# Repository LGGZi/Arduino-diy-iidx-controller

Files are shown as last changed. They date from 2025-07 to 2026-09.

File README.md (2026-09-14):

# Arduino-diy-iidx-controller
(README_EN.md for English)
学着lizardbeans佬写代码，使用超频A类似的外壳设计做的IIDX手台，LR2、beatoraja、和本家都可用，功能上包含HID灯光。自己做出来的成本在300-400（去除部分工具费用的话），视选用的配件具体数值会有波动，游玩的效果很不错，算得上便宜好用。<br>
2025/10/10更新：<br>
加入SDVX版代码和CAD文件，其中CAD文件的外壳在亚克力材质下可能有一定的强度问题。<br>
加入SDVX和IIDX通用的12键2编码器版本PCB和代码。
2026/9/5更新:<br>
废弃旧设计，目前仅维护新电路板内容。<br>
旧版readme可去文件名带有“_legacy”的readme查看
## 实物图
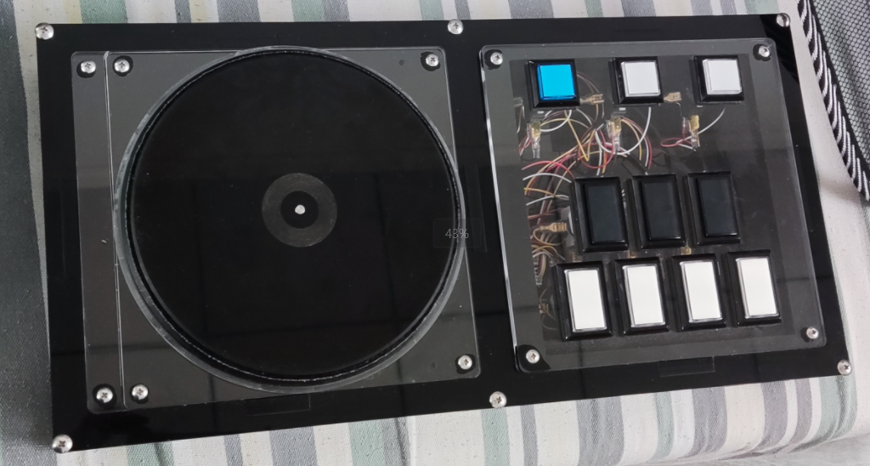
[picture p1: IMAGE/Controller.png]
<br><br>
## 目前已实现
1、一个画较为完善的电路板，嘉立创制作、原理图和PCB以及Gerber文件都放在`PCB&BOM`文件夹下。<br>
2、外壳的CAD文件。全亚克力外壳，包括转盘，转盘额外提供了一个可连接联轴器的版本，不需要的话不用切割。<br>
3、实现了多种输入模式的代码，具体功能在下一部分详细描述。<br>
## 控制器功能
1号键到4号键分别为不同模式，按住其中一个键并插入USB数据线即可进入不同模式，不同模式及其功能如下：<br>
------------------------------------------------------------------------------------<br>
* 模式1：手柄模拟量模式，此模式下会将按键映射为手柄的按钮，并将转盘映射为手柄x轴/y轴，转动转盘会视转动的方向和速度使手柄x轴/y轴平滑移动。<br>
* 模式2、3：三种不同灵敏度的手柄摇杆绝对值模式，按键与模式1相同，但转盘根据方向映射为按键和摇杆的极值，相当于是全按键模式。2和3模式区别为转盘灵敏度不同，2高敏，3低敏。<br>
* 模式4：键鼠模式，七个按键映射为键盘`z s x d c f v`，转盘映射为鼠标x轴和y轴，非常适合用于本家<br>

------------------------------------------------------------------------------------<br>
通过使用EEPROM实现了模式的记忆，插入时不选择模式（不按下按键）会从EEPROM中读取上次的模式并进入
可利用组合键开关灯光，开关灯光的函数为`lightswitch()`，默认为`(11,0,3,button_buf)`,即1、4、12按钮同时按下切换开关。
## 电路板使用说明
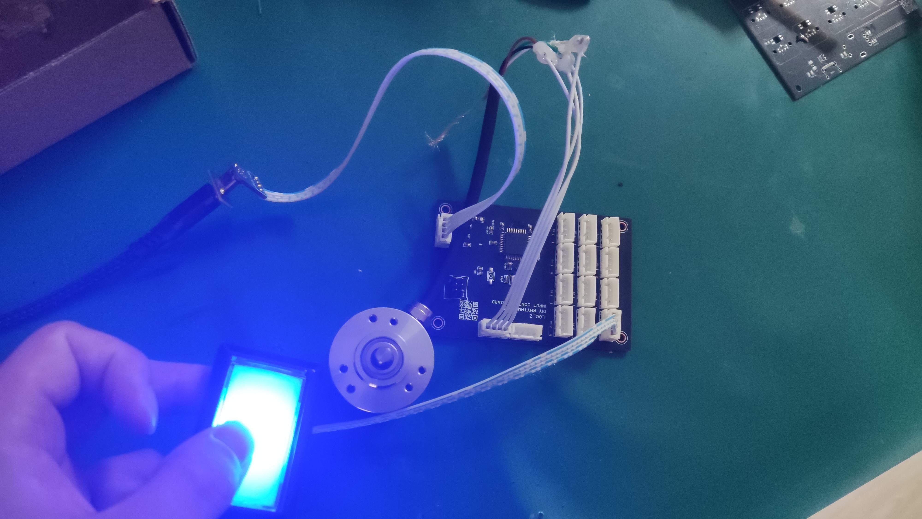
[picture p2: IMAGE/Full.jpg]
实物图<br><br>
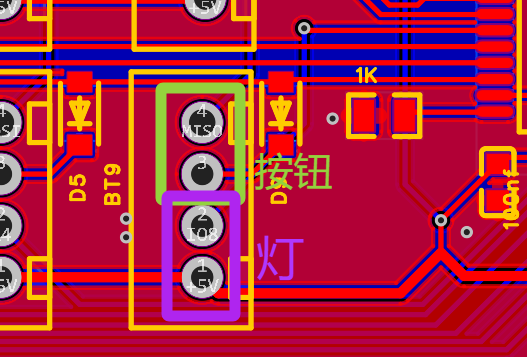
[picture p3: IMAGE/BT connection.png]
所有配件通过XH2.54的4pin借口连接，连接方式如下图<br><br>
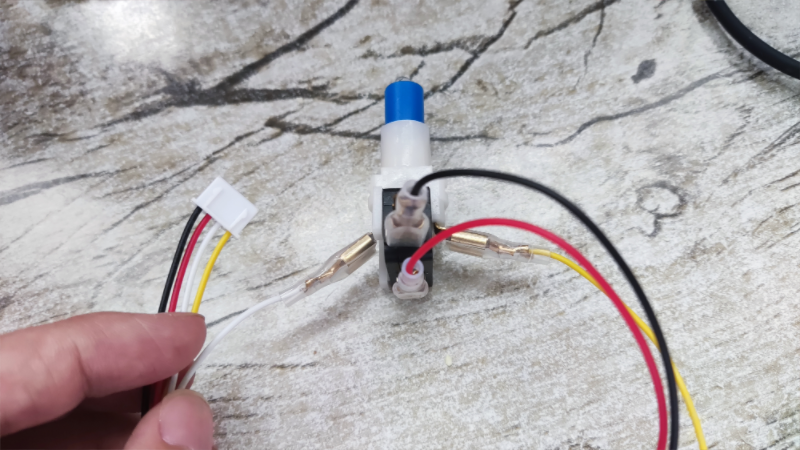
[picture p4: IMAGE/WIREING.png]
以按钮线举例如下图所示，公头防呆凸起面向上，左侧两个为连接微动的线，右侧两个为连接灯光的线，编码器的连接方式类似，根据上图连接即可<br><br>
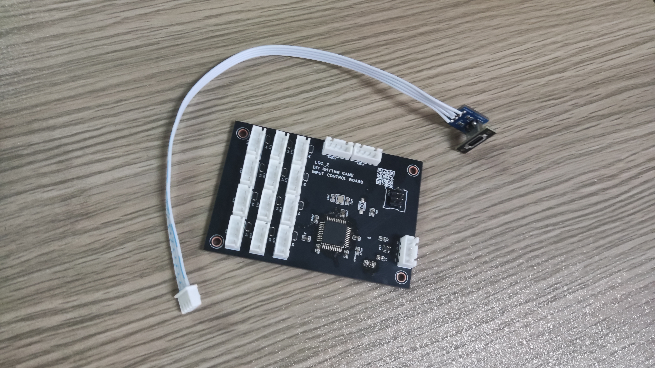
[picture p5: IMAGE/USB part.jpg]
USB部分以4Pin接口的形式引出，可外接USB模块<br><br>
USB模块的Gerber文件在`PCB&BOM`

## 外壳设计
全亚克力的外壳，框体板使用1cm亚克力切割，面板则在文件内标注了使用的亚克力厚度，转盘可与外壳共同切割，CAD内标注了防割倒角与螺丝孔用下沉，直接将CAD交付与激光切割的厂家即可。<br>
在框体之间的上下面板的螺丝孔之间加装50mm长的M4螺柱，这样即可实现上下板的连接和面板的安装<br>
转盘提供了使用法兰联轴器固定和仅依靠编码器D型轴柱联动的两种盘面，切割误差不太大的话仅依靠D型轴也能有不错的手感，只是因为盘体非固定的缘故不能倒置手台而已，由于编码器轴长和转盘盘座高度道问题，使用法兰联轴器版本的转盘可能需要额外使用垫片来下降编码器高度，否则转盘可能会悬空。<br>
我简单建模了一个转盘盘托，可以用3D打印机打印并代替CAD中的盘托文件在`3D_Model`中<br>
亚克力外壳分为大小两款，小款在`small`文件夹下，文件名带有3dprint的为使用3d打印盘托的外壳文件<br>

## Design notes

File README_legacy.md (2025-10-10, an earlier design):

# Arduino-diy-iidx-controller
(README_EN.md for English)
学着lizardbeans佬写代码，使用超频A类似的外壳设计做的IIDX手台，LR2、beatoraja、和本家都可用，功能上包含HID灯光。自己做出来的成本在300-400（去除部分工具费用的话），视选用的配件具体数值会有波动，游玩的效果很不错，算得上便宜好用。<br>
2025/10/10更新：<br>
加入SDVX版代码和CAD文件，其中CAD文件的外壳在亚克力材质下可能有一定的强度问题。<br>
加入SDVX和IIDX通用的12键2编码器版本PCB和代码。
## 实物图
<br><br>
## 目前已实现
1、一个画的很随便但可用的电路板，嘉立创制作、原理图和PCB以及Gerber文件都放在`PCB&BOM`文件夹下了。<br>
2、外壳的CAD文件。全亚克力外壳，包括转盘，转盘额外提供了一个可连接联轴器的版本，不需要的话不用切割。<br>
3、实现了多种输入模式的代码，具体功能在下一部分详细描述。<br>
## 控制器功能
按住start键（PCB上的BTA）加1到6号按键的其中一个键并插入USB数据线即可进入不同模式，不同模式及其功能如下：<br>
------------------------------------------------------------------------------------<br>
* 模式1：手柄模拟量模式，此模式下会将按键映射为手柄的按钮，并将转盘映射为手柄x轴，转动转盘会视转动的方向和速度使手柄x轴平滑移动。<br>
* 模式2-4：三种不同灵敏度的手柄摇杆绝对值模式，按键与模式1相同，但转盘根据方向映射为按键和摇杆的最左或最右，相当于是全按键模式。2到4三个模式区别为转盘灵敏度不同，2最快，4最慢。<br>
* 模式5：键鼠模式，七个按键映射为键盘zsxdcfv，转盘映射为鼠标x轴，非常适合用于本家<br>
* 模式6：自己搞着玩的，依旧是映射为键鼠，不过转盘换成了滚轮，别用。<br>

------------------------------------------------------------------------------------<br>
通过使用EEPROM实现了模式的记忆，插入时不按组合键会从EEPROM中读取上次的模式并进入

## 电路板使用说明
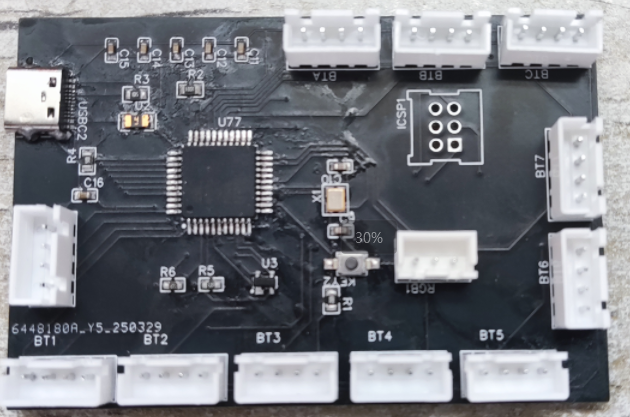
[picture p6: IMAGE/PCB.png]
实物图<br><br>
所有配件通过XH2.54的4pin借口连接，连接方式如下图<br><br>
以按钮线举例如下图所示，公头防呆凸起面向上，左侧两个为连接微动的线，右侧两个为连接灯光的线，编码器的连接方式类似，根据上图连接即可<br><br>
电路板上有可正反插的Type-C接口（虽然还是建议搞个延长线连外边用，有一种type-c延长线是刚好能卡在外壳侧板的开孔里的）

##外壳设计
全亚克力的外壳，框体板使用1cm亚克力切割，面板则在文件内标注了使用的亚克力厚度，转盘可与外壳共同切割，CAD内标注了防割倒角与螺丝孔用下沉，直接将CAD交付与激光切割的厂家即可。<br>
在框体之间的上下面板的螺丝孔之间加装50mm长的M4螺柱，这样即可实现上下板的连接和面板的安装<br>
转盘提供了使用法兰联轴器固定和仅依靠编码器D型轴柱联动的两种盘面，切割误差不太大的话仅依靠D型轴也能有不错的手感，只是因为盘体非固定的缘故不能倒置手台而已，由于编码器轴长和转盘盘座高度道问题，使用法兰联轴器版本的转盘可能需要额外使用垫片来下降编码器高度，否则转盘可能会悬空。<br>
（附图等之后再此下单买外壳的时候再拍）<br>

## 代码结构
以后再施工，懒了💀

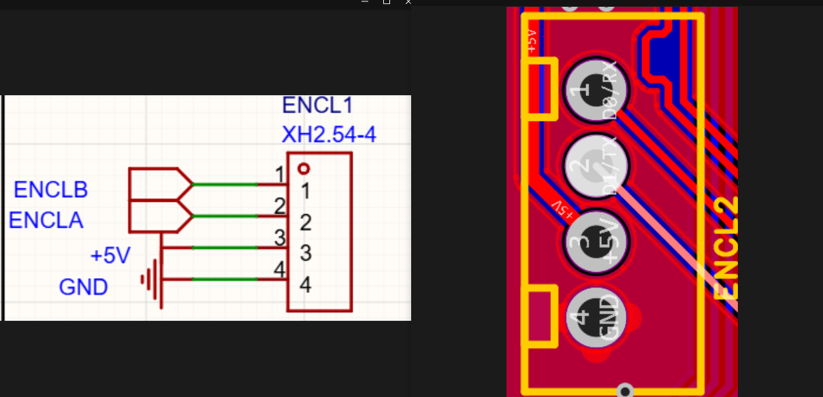
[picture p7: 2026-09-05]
IMAGE/Encoder connection.png

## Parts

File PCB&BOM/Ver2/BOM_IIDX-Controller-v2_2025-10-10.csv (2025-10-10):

ID | Name | Designator | Footprint | Quantity | Manufacturer Part | Manufacturer | Supplier | Supplier Part | Price
1 | XH2.54-4 | BT1,BT2,BT3,BT4,BT5,BT6,BT7,BT8,BT9,BTA,BTB,BTC,ENCL1,ENCL2,USB | CONN-TH_XH2.54-4 | 15 | XH2.54-4 | null | LCSC | C9900012082
2 | 22pF | C9,C10 | C0603 | 2 | CL10C220JB81PNC | SAMSUNG | LCSC | C170132 | 0.066
3 | 100nF | C11,C12,C13,C14 | C0603 | 4 | CL10B104JB8NNNC | SAMSUNG | LCSC | C24452 | 0.0591
4 | 470nF | C15 | C0603 | 1 | CL10B474KA8NNNC | SAMSUNG | LCSC | C1623 | 0.0461
5 | 1uF | C16 | C0603 | 1 | CL10A105KB8NNNC | SAMSUNG | LCSC | C15849 | 0.0311
6 | SOD4002-SH | D1,D2,D3,D4,D5,D6,D7,D8,D9,DA,DB,DC | SOD-123F_L2.8-W1.8-LS3.7-RD | 12 | SOD4002-SH | LRC(乐山无线电) | LCSC | C154996 | 0.1075
7 | XH2_54-2X3P直插 | ICSP1 | CONN-TH_XH2.54-2X3P | 1 | XH2_54-2X3P直插 | null | LCSC | C9900001046
8 | Switch3x4x2 | KEY2 | KEY-3.0*4.0 | 1 | Switch3x4x2 | ReliaPro | LCSC | C26638 | 0.1628
9 | 10K | R1 | R0805 | 1 | 0805W8F1002T5E | UniOhm | LCSC | C17414 | 0.0114
10 | 1K | R2 | R0805 | 1 | TC0525F1001T5E | UniOhm | LCSC | C75781 | 0.0776
11 | 22 | R5,R6 | R0603 | 2 | 0603WAF220JT5E | UniOhm | LCSC | C23345 | 0.0062
12 | 铜柱M3*12+3 | U1,U4,U5,U6 | TH_BD4.7-D3.0 | 4 | M3*12+3 | 国产 | LCSC | C110574 | 0.2255
13 | MF-NSMF050-2 | U2 | F1206 | 1 | MF-NSMF050-2 | BOURNS | LCSC | C75464 | 0.1976
14 | PRTR5V0U2X | U3 | SOT-143_L2.9-W1.3-P1.92-LS2.3-BL | 1 | PRTR5V0U2X | Yenji Elec | LCSC | C330092 | 0.5828
15 | ATMEGA32U4-AU | U77 | QFP-44_L10.0-W10.0-P0.80-LS13.2-BL | 1 | ATMEGA32U4-MU | MICROCHIP | LCSC | C112161 | 34.13
16 | 16MHz | X1 | OSC-SMD_4P-L3.2-W2.5-BL | 1 | X322516MRB4SI | YXC | LCSC | C70562 | 0.5159

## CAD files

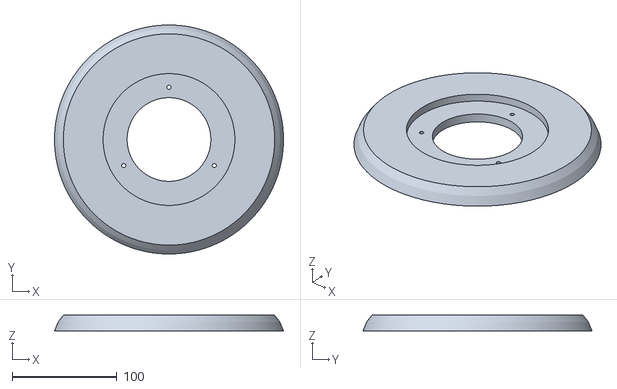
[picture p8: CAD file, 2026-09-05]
3D_Model/Ttable15mmhigh.stl
219.0 x 219.0 x 15.0

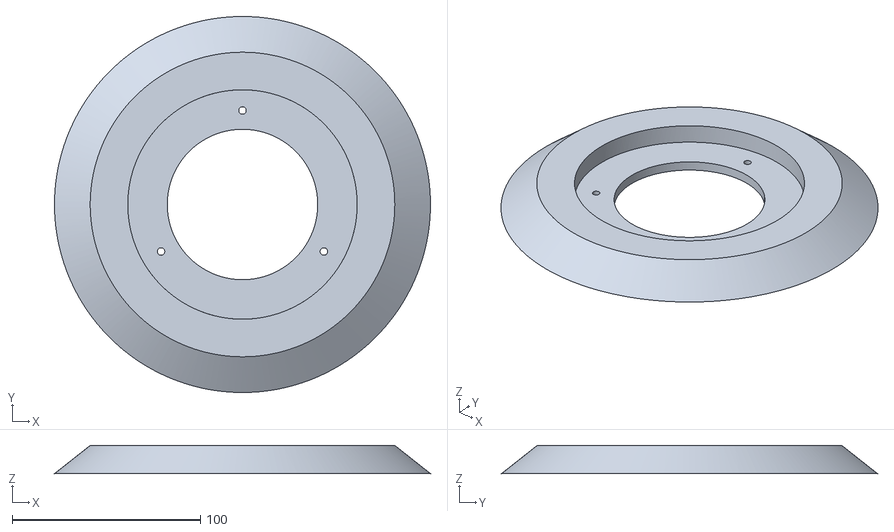
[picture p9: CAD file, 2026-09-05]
3D_Model/Ttable160TT 15hight.stl
200.0 x 200.0 x 15.0

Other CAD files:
Frame_cad/SDVX/FULL FRAME.dwg
Frame_cad/IIDX/panel 0.45cm mostly with 3dprint.dwg
Frame_cad/IIDX/small/drawing_frame_v3.dwg
Frame_cad/IIDX/frame plastic 1cm type-c.dwg
Frame_cad/IIDX/small/drawing_panel_v2_200TT_10key.dwg
Frame_cad/IIDX/frame plastic 1cm.dwg
Frame_cad/IIDX/small/drawing_panel_160TT_3dprint_10key.dwg
Frame_cad/IIDX/panel 0.45cm mostly.dwg
3D_Model/Ttable15mmhigh.dwg

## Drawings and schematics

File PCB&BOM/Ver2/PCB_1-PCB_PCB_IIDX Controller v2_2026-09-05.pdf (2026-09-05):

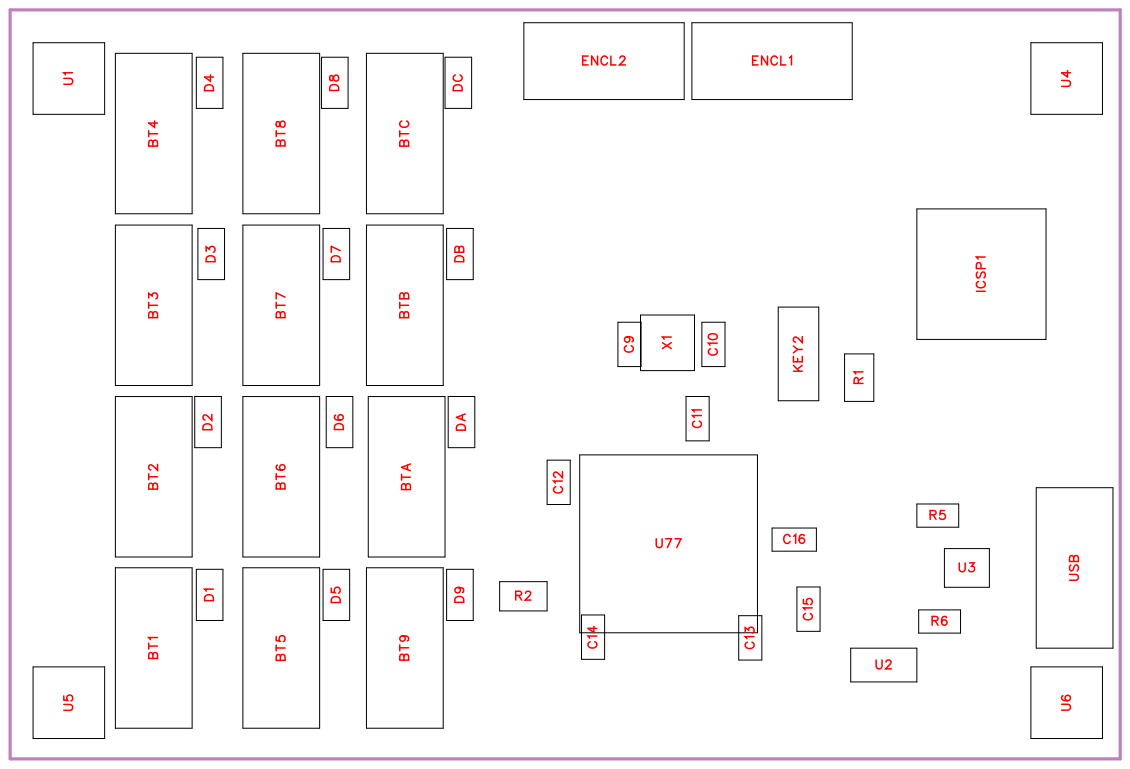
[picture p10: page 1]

No. | Quantity | Comment | Designator | Footprint | Value | Manufacturer Part | Manufacturer | Supplier Part | Supplier
1 | 15 | XH2.54-4 | BT1,BT2,BT3,BT4,BT5,BT6 ,BT7,BT8,BT9,BTA,BTB,BT C,ENCL1,ENCL2,USB | CONN-TH_X H2.54-4 | | XH2.54-4 | null | C990001208 2 | LCSC
2 | 2 | 22pF | C9,C10 | C0603 | | CL10C220JB 81PNC | SAMSUNG | C170132 | LCSC
3 | 4 | 100nF | C11,C12,C13,C14 | C0603 | | CL10B104JB 8NNNC | SAMSUNG | C24452 | LCSC
4 | 1 | 470nF | C15 | C0603 | | CL10B474KA 8NNNC | SAMSUNG | C1623 | LCSC
5 | 1 | 1uF | C16 | C0603 | | CL10A105KB 8NNNC | SAMSUNG | C15849 | LCSC
6 | 12 | SOD4002-S H | D1,D2,D3,D4,D5,D6,D7,D8, D9,DA,DB,DC | SOD-123F_L 2.8-W1.8-LS 3.7-RD | | SOD4002-S H | LRC(乐山无 线电) | C154996 | LCSC
7 | 1 | XH2_54-2X3 P直插 | ICSP1 | CONN-TH_X H2.54-2X3P | | XH2_54-2X3 P直插 | null | C990000104 6 | LCSC
8 | 1 | Switch3x4x2 | KEY2 | KEY-3.0*4.0 | | Switch3x4x2 | ReliaPro | C26638 | LCSC
9 | 1 | 10K | R1 | R0805 | | 0805W8F100 2T5E | UniOhm | C17414 | LCSC
10 | 1 | 1K | R2 | R0805 | | TC0525F100 1T5E | UniOhm | C75781 | LCSC
11 | 2 | 22 | R5,R6 | R0603 | | 0603WAF22 0JT5E | UniOhm | C23345 | LCSC
12 | 4 | 铜柱M3*12+3 | U1,U4,U5,U6 | TH_BD4.7-D 3.0 | | M3*12+3 | 国产 | C110574 | LCSC
13 | 1 | MF-NSMF05 0-2 | U2 | F1206 | | MF-NSMF05 0-2 | BOURNS | C75464 | LCSC
14 | 1 | PRTR5V0U2 X | U3 | SOT-143_L2. 9-W1.3-P1.9 2-LS2.3-BL | | PRTR5V0U2 X | Yenji Elec | C330092 | LCSC
15 | 1 | ATMEGA32U 4-AU | U77 | QFP-44_L10. 0-W10.0-P0. 80-LS13.2-B L | | ATMEGA32U 4-MU | MICROCHIP | C112161 | LCSC
16 | 1 | 16MHz | X1 | OSC-SMD_4 P-L3.2-W2.5-BL | | X322516MR B4SI | YXC | C70562 | LCSC

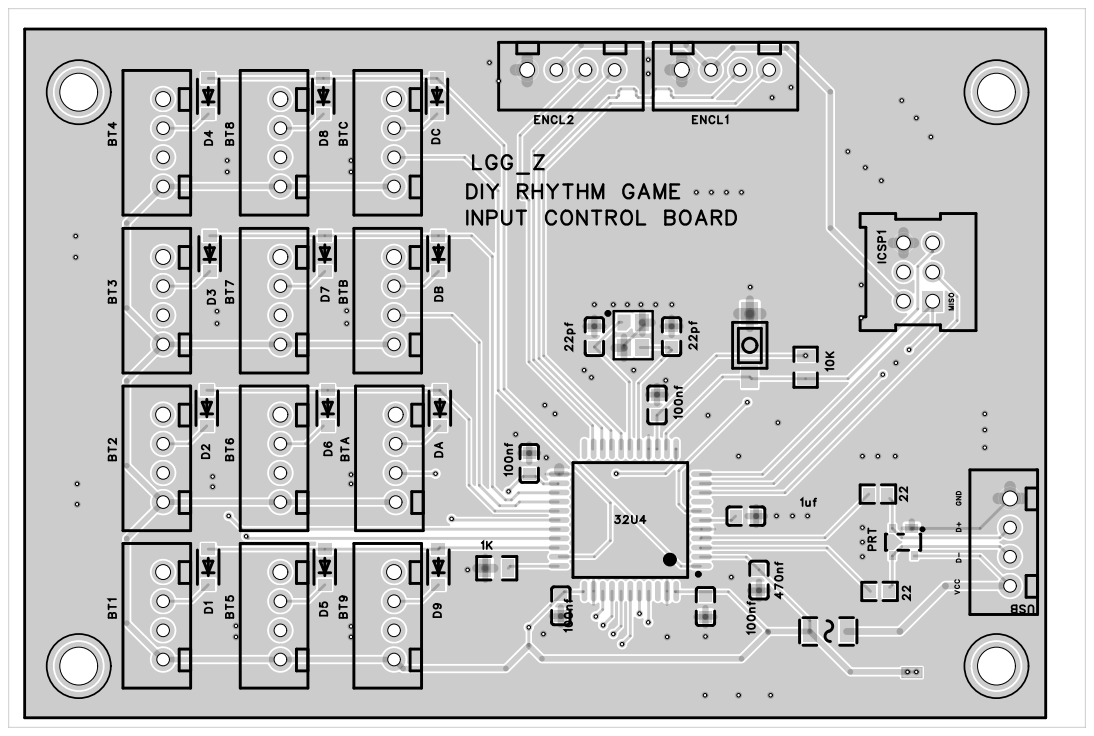
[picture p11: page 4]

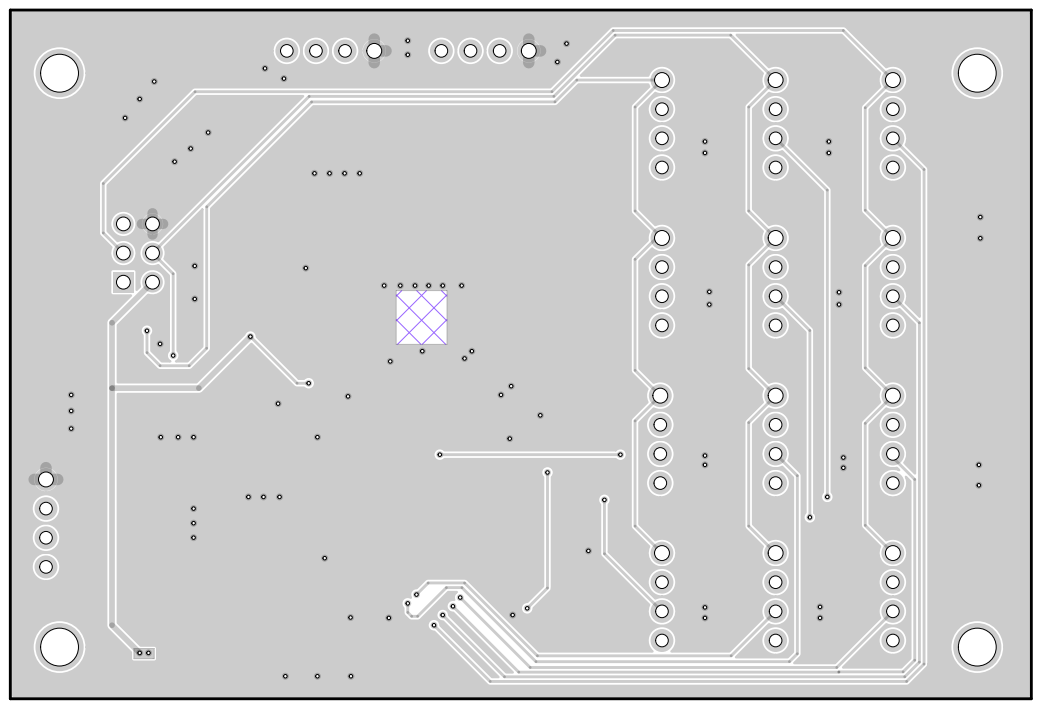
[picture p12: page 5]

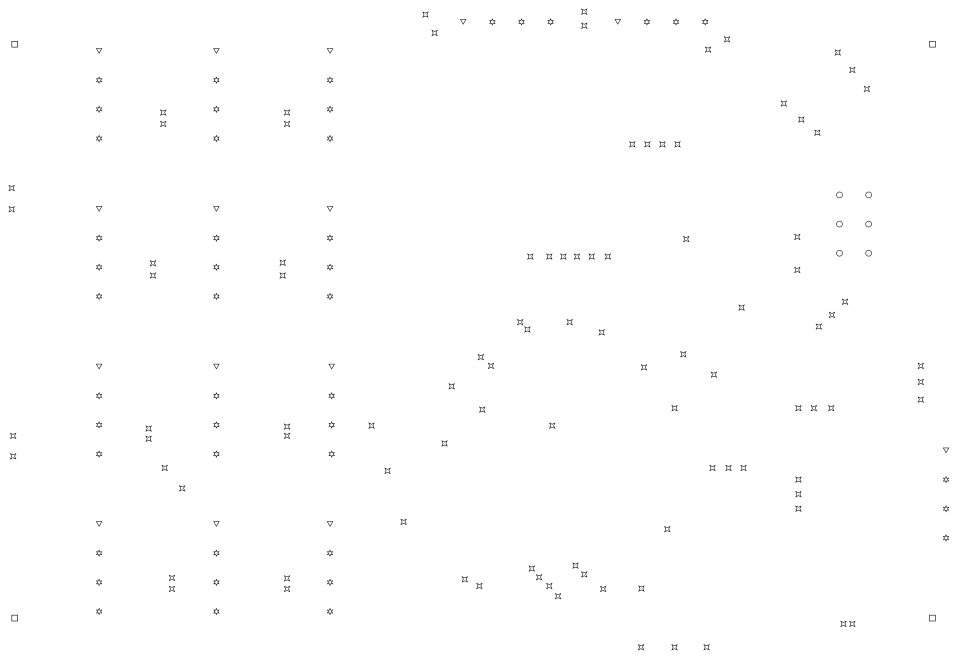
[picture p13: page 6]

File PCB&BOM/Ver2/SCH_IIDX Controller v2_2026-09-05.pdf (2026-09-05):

# ICSP

# ATMEGA32U4

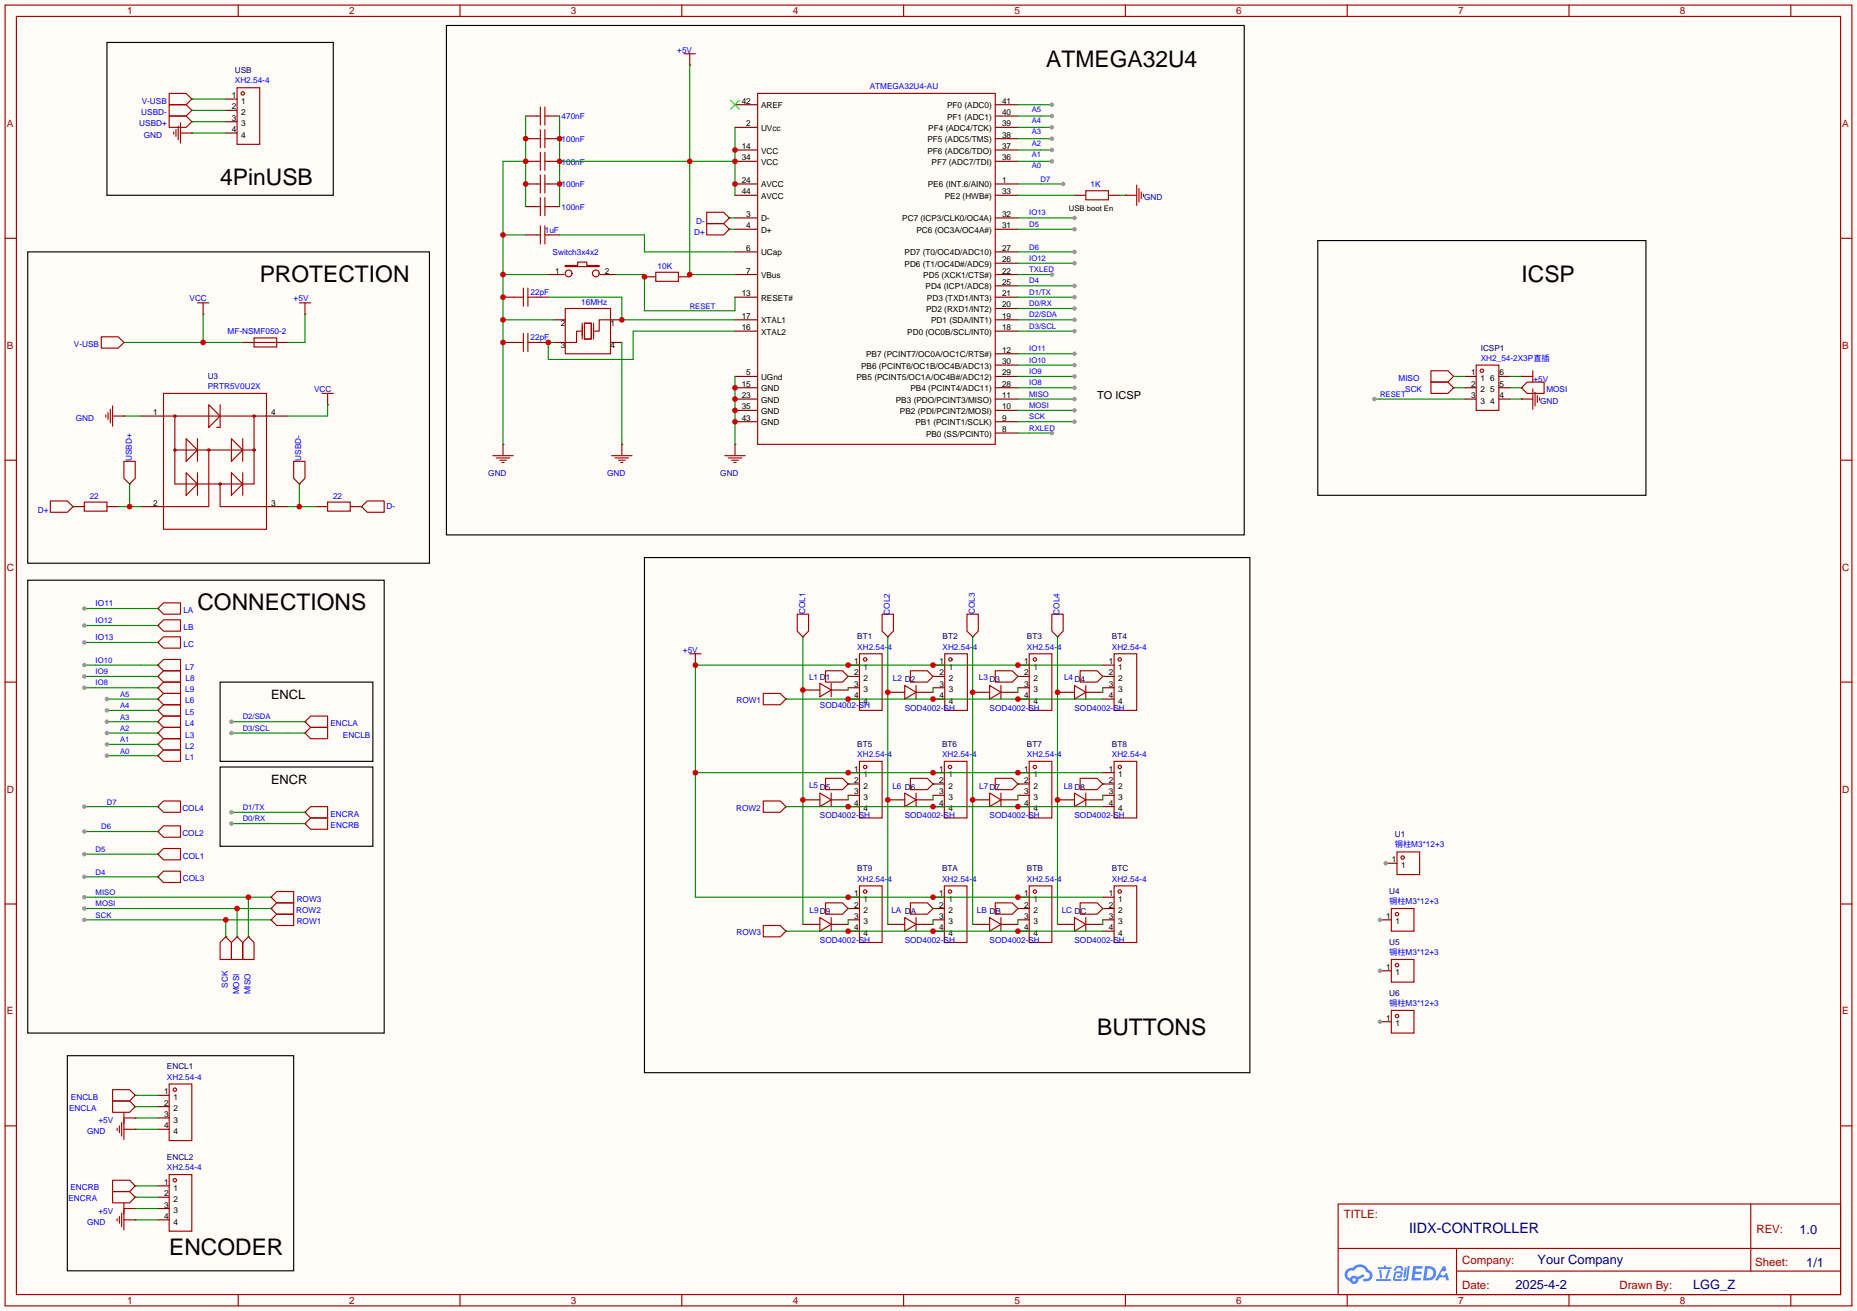
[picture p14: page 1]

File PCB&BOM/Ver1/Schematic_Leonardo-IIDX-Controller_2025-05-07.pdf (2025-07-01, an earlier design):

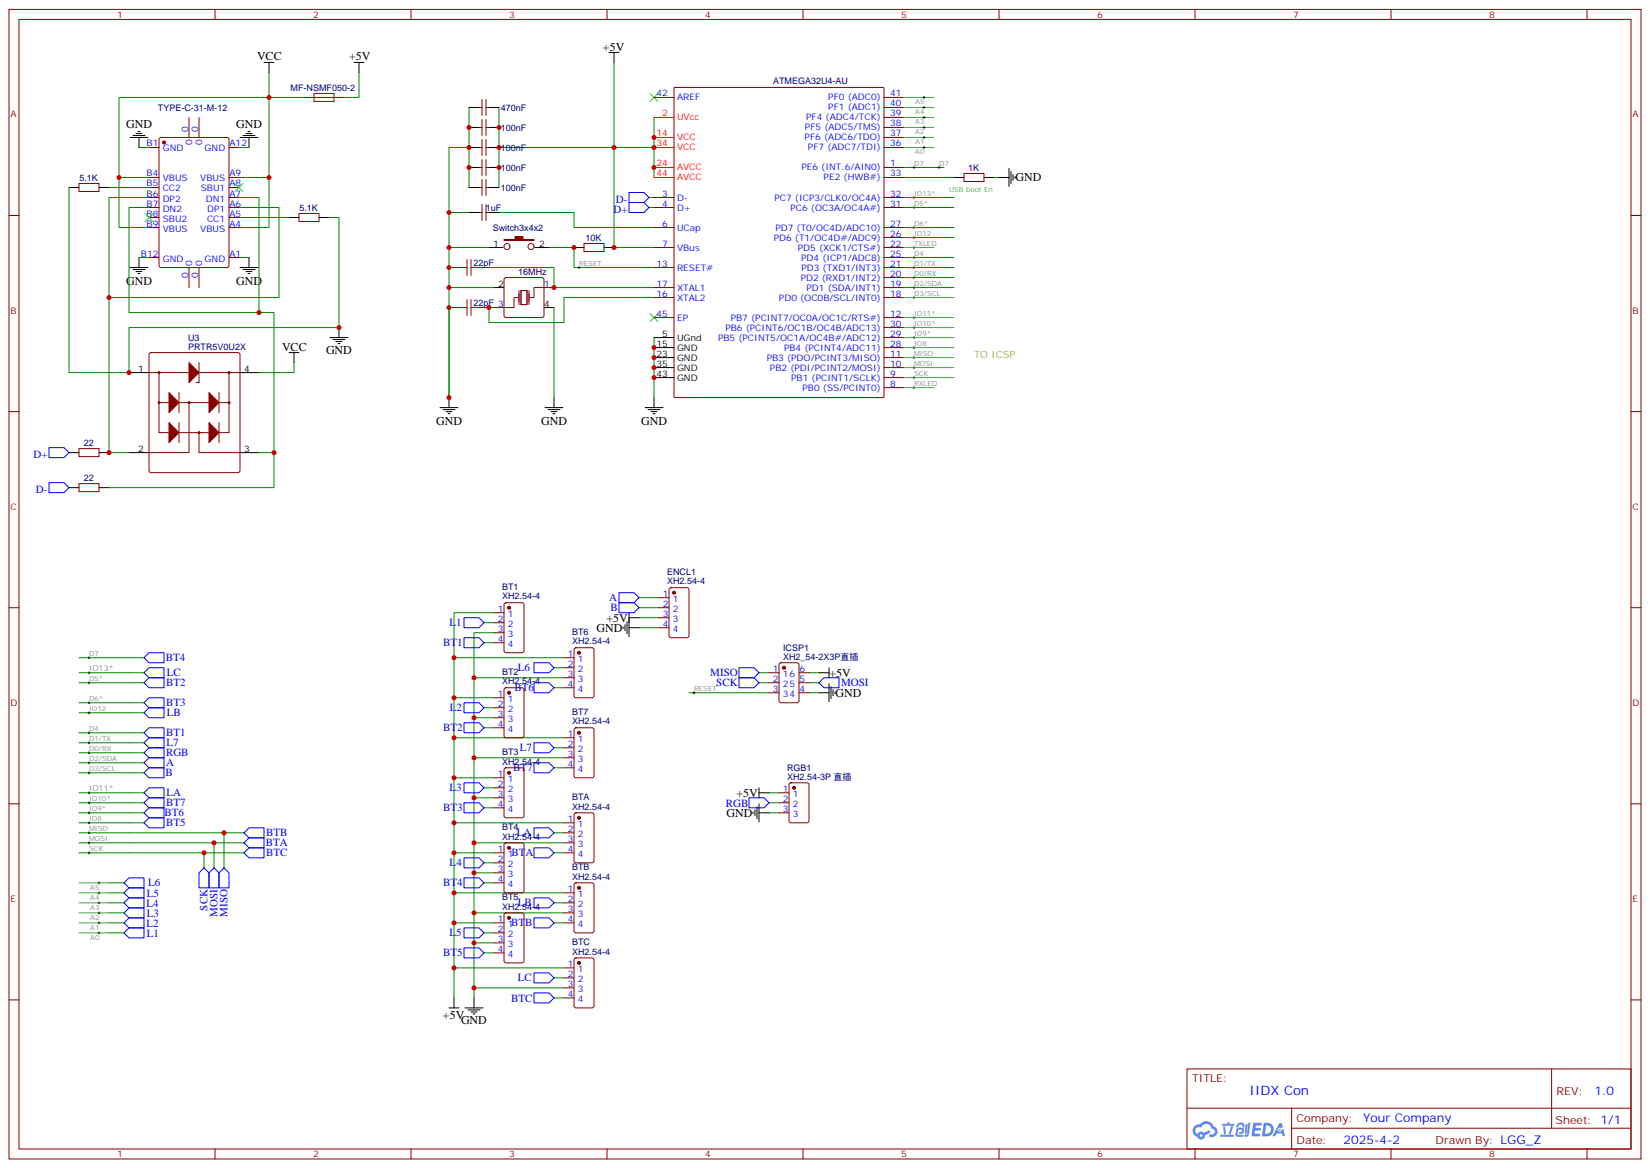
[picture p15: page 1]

ATMEGA32U4-AU
PF7 (ADC7/TDI) 36 PF6 (ADC6/TDO) 37 PF5 (ADC5/TMS) 38 PF4 (ADC4/TCK) 39 PF1 (ADC1) 40 PF0 (ADC0) 41

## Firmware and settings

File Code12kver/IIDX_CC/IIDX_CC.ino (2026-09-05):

#include "SubHID.h"
#include <EEPROM.h>
#include "iidx_Controller.h"
#include "iidx_Keyboard_N_Mouse.h"
extern volatile HIDConReport_t report;
extern volatile uint16_t HIDCon_led;
extern volatile uint8_t ledPins[];
extern volatile uint8_t buttonPins[];
extern volatile uint16_t ledbuf;
extern volatile uint16_t buttonstate;
extern volatile int lighton;


uint8_t mode = 0;
//模式选择
void mode_select(uint8_t modecode) {
  if (modecode >= 1 && modecode <= 3) {
    use_Controller_style(modecode);
  } else {
    use_KeyboardMouse_style(modecode);
  }
}
//初始化
void setup() {
  // Serial.begin(9600);
  delay(1000);
  for (int i = 0; i < sizeof(col_bt); i++) {
    pinMode(col_bt[i], INPUT_PULLUP);
  }
  for (int i = 0; i < sizeof(row_bt); i++) {
    pinMode(row_bt[i], OUTPUT);
  }
  for (int i = 0; i < sizeof(ledPins); i++) {
    pinMode(ledPins[i], OUTPUT);
  }
  pinMode(ENC_L_A, INPUT_PULLUP);
  pinMode(ENC_L_B, INPUT_PULLUP);
  pinMode(ENC_R_A, INPUT_PULLUP);
  pinMode(ENC_R_B, INPUT_PULLUP);
  //初始选择模式的部分
  buttonstate = button_scan();
  delay(100);
  buttonstate &= button_scan();
  Serial.println(buttonstate);
  if (((buttonstate >> 0) & 1)) {
    EEPROM.write(0, 1);
  } else if (((buttonstate >> 1) & 1)) {
    EEPROM.write(0, 2);
  } else if (((buttonstate >> 2) & 1)) {
    EEPROM.write(0, 3);
  } else if (((buttonstate >> 3) & 1)) {
    EEPROM.write(0, 4);
  } else if (((buttonstate >> 4) & 1)) {
    EEPROM.write(0, 5);
  } else if ((EEPROM.read(0) < 0) | (EEPROM.read(0) > 6)) {
    EEPROM.write(0, 1);
  }
  //EEPROM.write(0, 1);
  EEPROM.get(0, mode);
  mode_select(mode);
}

void loop() {
  //主程序选择
  if (mode >= 1 && mode <= 3) {
    using_Controller_style();
  } else {
    using_KeyboardMouse_style();
  }
  lights(ledbuf);

  //每周期一次的report结构内容的上传
  HIDCon.setState(&report);
}

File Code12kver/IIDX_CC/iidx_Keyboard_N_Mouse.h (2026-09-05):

#include "Universal.h"

extern volatile HIDConReport_t report;
extern volatile uint16_t HIDCon_led;
extern volatile uint8_t ledPins[];
extern volatile uint8_t muiltPins[][3];
extern volatile uint16_t ledbuf;
extern volatile uint16_t buttonstate;
extern volatile int lighton;
extern volatile int32_t encL;
extern volatile int32_t encR;
extern volatile uint8_t max_bt;

int32_t pre_encL = 0;
int32_t diff_encL = 0;
int32_t pre_encR = 0;
int32_t diff_encR = 0;
uint16_t buttonstate_now;
 uint8_t kstopFlagL = 0;
 uint8_t kstopFlagR = 0;
 uint8_t kstopThreshold = 0;
 int knumSTARTENCL = 4;
 int kstartencl = 0;
 int kstartencR = 0;
int keys[]{41,34,39,19,18,21,37,42,43,44,45,46};
int key_map[sizeof(col_bt)*sizeof(row_bt)+2][2] = {0};
int keys1[]{16,34,19,56,25,24,30,22,23,44,45,46};

// uint8_t TT_addr = 0;
unsigned long time_Now = 0;
unsigned long time_Pre[sizeof(col_bt)*sizeof(row_bt)] = {0};
uint8_t modekeyboard;
void Encl_mouse(){
  //简单的将编码器脉冲顺增逆减后储存在encL里
  //Serial.print("+p");
  //startencl++;
  //if(startencl>numSTARTENCL){
  if (digitalRead(ENC_L_A) != HIGH) {
    //Serial.print("++");
    // TT_addr = 1;
    encL ++ ;
  } else {
    //Serial.print("__");
    // TT_addr = -1;
    encL -- ;
    }
}
//}
void EncR_mouse(){
  //简单的将编码器脉冲顺增逆减后储存在encL里
  //Serial.print("+p");
  //startencl++;
  //if(startencl>numSTARTENCL){
  if (digitalRead(ENC_R_A) != HIGH) {
    //Serial.print("++");
    // TT_addr = 1;
    encR ++ ;
  } else {
    //Serial.print("__");
    // TT_addr = -1;
    encR -- ;
    }
}
//}
void keycode_find(){
  //键值转化函数，键盘报文以8位为一组，此函数将键值计算以寻找到其在report.keyboardKeys[]对应位置角标和bit位置
  for(int i=0;i<max_bt+2;i++){
    key_map[i][0] = keys[i] / 8;
    key_map[i][1] = keys[i] % 8;
    // delay(1000);
    // Serial.println("key_mapi");
    // Serial.println(key_map[i][0]);
    // Serial.println(key_map[i][1]);
  }
}
void keycode_find1(){
  //键值转化函数，键盘报文以8位为一组，此函数将键值计算以寻找到其在report.keyboardKeys[]对应位置角标和bit位置
  for(int i=0;i<max_bt+2;i++){
    key_map[i][0] = keys1[i] / 8;
    key_map[i][1] = keys1[i] % 8;
    // delay(1000);
    // Serial.println("key_mapi");
    // Serial.println(key_map[i][0]);
    // Serial.println(key_map[i][1]);
  }
}
void kEncL_AbsoluteOn(){
  //绝对值模式的正反转检测与按键映射
  kstopFlagL = 0;
  kstartencl++;
  if(kstartencl>knumSTARTENCL){
    if (digitalRead(ENC_L_A) != HIGH) {
      report.keyboardKeys[-2] |= ((uint8_t)1 << 0);
      report.keyboardKeys[-2] &= ~((uint8_t)1 << 1);
    } else {
      report.keyboardKeys[-2] |= ((uint8_t)1 << 1);
      report.keyboardKeys[-2] &= ~((uint8_t)1 << 0);
    }
  }
}
void kEncR_AbsoluteOn(){
  //绝对值模式的正反转检测与按键映射
  kstopFlagR = 0;
  kstartencR++;
  if(kstartencR>knumSTARTENCL){
    if (digitalRead(ENC_R_A) != HIGH) {
      report.keyboardKeys[-2] |= ((uint8_t)1 << 4);
      report.keyboardKeys[-2] &= ~((uint8_t)1 << 5);
    } else {
      report.keyboardKeys[-2] |= ((uint8_t)1 << 5);
      report.keyboardKeys[-2] &= ~((uint8_t)1 << 4);
    }
  }
}
void kEncL_AbsoluteOff(){
  //绝对值模式的归中函数
  if(kstopFlagL < kstopThreshold){
      kstopFlagL++;
    } else {
      report.keyboardKeys[-2] &= ~((uint8_t)1 << 0);
      report.keyboardKeys[-2] &= ~((uint8_t)1 << 1);
      kstartencl=0;
    }
}
void kEncR_AbsoluteOff(){
  //绝对值模式的归中函数
  if(kstopFlagR < kstopThreshold){
      kstopFlagR++;
    } else {
      report.keyboardKeys[-2] &= ~((uint8_t)1 << 4);
      report.keyboardKeys[-2] &= ~((uint8_t)1 << 5);
      kstartencR=0;
    }
}

void use_KeyboardMouse_style(uint8_t modecode){
  if(modecode == 4){
    lights_test(modecode);
    attachInterrupt(digitalPinToInterrupt(ENC_L_B), Encl_mouse, RISING);
    attachInterrupt(digitalPinToInterrupt(ENC_R_B), EncR_mouse, RISING);
    knumSTARTENCL=0;
    keycode_find();
    report.lyAxis = -128;
  }else  if(modecode == 5){
    lights_test(modecode);
    kstopThreshold = 3; 
    knumSTARTENCL=1;
    attachInterrupt(digitalPinToInterrupt(ENC_L_B), kEncL_AbsoluteOn, RISING);
    attachInterrupt(digitalPinToInterrupt(ENC_R_B), kEncR_AbsoluteOn, RISING);
    keycode_find();
    report.lyAxis = -128;
  }
  modekeyboard = modecode;
}
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

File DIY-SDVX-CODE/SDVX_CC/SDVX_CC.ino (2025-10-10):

#include "SubHID.h"
#include <EEPROM.h>
#include "sdvx_Controller.h"
#include "sdvx_Keyboard_N_Mouse.h"
extern volatile HIDConReport_t report;
extern volatile uint16_t HIDCon_led;
extern volatile uint8_t ledPins[];
extern volatile uint8_t buttonPins[];
extern volatile uint8_t muiltPins[][3];
extern volatile uint16_t ledbuf;
extern volatile uint16_t buttonbuf;
extern volatile int lighton;


uint8_t mode = 0;
//模式选择
void mode_select(uint8_t modecode){
  if(modecode >= 1 && modecode <= 4){
    use_Controller_style(modecode);
  }else{
    use_KeyboardMouse_style(modecode);
  }
}
//初始化
void setup() {
  delay(1000);
  // Setup I/O for pins
  for(int i=0;i<BUTTONCOUNT;i++){
    pinMode(buttonPins[i],INPUT_PULLUP);
    pinMode(ledPins[i],OUTPUT);
  }
  pinMode(ENC_L_A,INPUT_PULLUP);
  pinMode(ENC_L_B,INPUT_PULLUP);
  pinMode(ENC_R_A,INPUT_PULLUP);
  pinMode(ENC_R_B,INPUT_PULLUP);
  //初始选择模式的部分
  if(digitalRead(muiltPins[0][0]) != HIGH && digitalRead(muiltPins[0][1]) != HIGH ) 
  { 
    EEPROM.write(0, 1);
  }
  else if(digitalRead(muiltPins[1][0]) != HIGH && digitalRead(muiltPins[1][1]) != HIGH ) 
  {
    EEPROM.write(0, 2);
  }
  else if(digitalRead(muiltPins[2][0]) != HIGH && digitalRead(muiltPins[2][1]) != HIGH ) 
  {
    EEPROM.write(0, 3);
  }
  else if(digitalRead(muiltPins[3][0]) != HIGH && digitalRead(muiltPins[3][1]) != HIGH ) 
  {
    EEPROM.write(0, 4);
  }  
  else if(digitalRead(muiltPins[4][0]) != HIGH && digitalRead(muiltPins[4][1]) != HIGH ) 
  {
    EEPROM.write(0, 5);
  }
  // else if(digitalRead(muiltPins[5][0]) != HIGH && digitalRead(muiltPins[5][1]) != HIGH ) 
  // {
  //   EEPROM.write(0, 6);
  // }
  //EEPROM.write(0, 3);
  EEPROM.get(0 , mode);
  mode_select(mode);
  // Serial.begin(9600);
}

void loop() {
  //主程序选择
  if(mode >= 1 && mode <= 4){
    using_Controller_style();
  }else{
    using_KeyboardMouse_style();
  }
  lights(ledbuf);

  //灯光开关
  lightswitch(6);
  //每周期一次的report结构内容的上传
  HIDCon.setState(&report);
}

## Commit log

2025-07-05 canceled ENCODER_SENSITIVITY
    canceled ENCODER_SENSITIVITY, use ENCODER_PULSE_TIMES instead
2025-10-10 12key、2encoder version PCB updated
    [BOM_IIDX-Controller-v2_2025-10-10.csv, BOM_Leonardo-IIDX-Controller_2025-07-05.csv, PCB_32u4最小系统-copy_2025-07-01.pcbdoc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]
2025-10-10 Update SDVX cad file, However.
    Update SDVX cad file, However, the physical strenth of the frame are not promised
    [FULL FRAME.dwg, frame plastic 1cm type-c.dwg, frame plastic 1cm.dwg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]
2026-09-05 edit pin layout
2026-09-05 edit pin layout and fixed crystal failure
2026-09-05 Add 3d_print TT Lifter model
    [drawing_frame_v3.dwg, drawing_panel_160TT_3dprint_10key.dwg, drawing_panel_v2_200TT_10key.dwg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]
2026-09-05 Revise README with updates on controller design
    Updated README.md with new information on the controller design and features, including the removal of old designs and the addition of new PCB details and 3D model files.
2026-09-05 Update PCB image in README.md
2026-09-07 Document light switch functionality in README
    Added functionality to switch lights using a combination of buttons.
2026-09-07 Revise README with updates and new features
    Updated README to reflect changes in design and features, including new PCB and CAD files for SDVX compatibility. Added updates for deprecated designs and clarified controller functions and assembly 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
